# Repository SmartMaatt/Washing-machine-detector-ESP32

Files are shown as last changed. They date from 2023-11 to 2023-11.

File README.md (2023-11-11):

<h1 align="center">
    Alarm Amplifier Project
</h1>

<p align="center">
  <a href="#overview">Overview</a> •
  <a href="#hardware">Hardware</a> •
  <a href="#software">Software</a> •
  <a href="#usage-guide">Usage Guide</a> •
  <a href="#testing-and-troubleshooting">Testing and Troubleshooting</a> •
  <a href="#license">License</a>
</p>

<p align="center">
  
  
</p>

## Overview

This project involves the development of an alarm amplifier system designed to monitor the light status of household appliances using photoresistors. It reacts to changes in light with an audio alarm and Bluetooth console notifications. The system is built around the ESP32 microcontroller, incorporating features like Wi-Fi and Bluetooth connectivity.

## Hardware

### Components

- **ESP32 Microcontroller**: Central processing unit of the system, equipped with Wi-Fi and Bluetooth modules.
- **MAX99357 Audio Amplifier**: Converts digital signals into analog sound for the speaker.
- **Photoresistors**: Detects the light status from household appliances.
- **10kOhm Resistors**: Used in conjunction with the photoresistors to create a voltage divider.
- **B3F-1000S Button**: Manual reset button for the alarm system.

Hardware Components Image
*Hardware Components*

### Circuit Diagram

The following is the circuit diagram of the alarm amplifier system:

Circuit Diagram Image
*Circuit Diagram*

## Software

### Source Code

The project's source code is written in C and utilizes the Arduino IDE for development. Key libraries include:

- `AudioOutputI2S.h`
- `AudioFileSourcePROGMEM.h`
- `AudioGeneratorFLAC.h`
- `BluetoothSerial.h`

### Main Functionalities

- **Initial Setup**: Initializes the system and sets up Bluetooth and audio configurations.
- **Loop Function**: Manages the reading of sensor data, Bluetooth inputs, and alarm triggering.
- **Alarm Management**: Handles the audio alarm based on sensor input and allows manual reset.

### Bluetooth Commands

- `input1`, `input2`, `input3`: Activate/deactivate specific sensors.
- `ShowData`: Display current sensor data and status.
- `stop`: Stop the current alarm.

## Installation and Setup

To install and set up the software on your ESP32 microcontroller, follow these steps:

1. **Software Requirements**:
   - Ensure you have the latest version of the Arduino IDE installed on your computer. It can be downloaded from the [Arduino website](https://www.arduino.cc/en/software).

2. **ESP32 Board Manager Installation**:
   - Open the Arduino IDE.
   - Go to File > Preferences and in the "Additional Board Manager URLs" field, add the following URL: `https://dl.espressif.com/dl/package_esp32_index.json`.
   - Open the Board Manager by going to Tools > Board > Boards Manager, search for ESP32, and install the latest version.

3. **Connect the ESP32 to Your Computer**:
   - Using a micro USB cable, connect the ESP32 to your computer. Ensure that the ESP32 is powered on.

4. **Select the Correct Board and Port**:
   - In the Arduino IDE, go to Tools > Board and select the appropriate ESP32 board (e.g., ESP32 Dev Module).
   - Go to Tools > Port and select the COM port that the ESP32 is connected to.

5. **Load the Software**:
   - Open the project source code in the Arduino IDE.
   - If any additional libraries are required (as mentioned in the Software section), make sure they are installed.

6. **Compile and Upload**:
   - Click the "Upload" button in the Arduino IDE to compile the code and upload it to the ESP32.
   - Wait for the message "Done uploading" to appear in the IDE's console window.

7. **Verify Operation**:
   - After the code is successfully uploaded, the ESP32 should start running the program.
   - Monitor the Serial Monitor in the Arduino IDE for any debug information or confirmation messages.

8. **Bluetooth Pairing**:
   - On your smartphone or Bluetooth-enabled device, turn on Bluetooth and search for new devices.
   - Find the "Washing Machine Detector" and pair with it.
   - Once paired, you can use Bluetooth terminal applications to send commands to the ESP32.

If you encounter any issues during installation, refer to the Troubleshooting section for guidance.

## Usage Guide

To effectively utilize the alarm amplifier system, follow these steps:

1. **Power Connection**: Connect the system to a power source using the micro USB port on the ESP32.
2. **Mounting**: Attach the system near your chosen appliance, ensuring the photoresistors are positioned to accurately detect the appliance's light status.
3. **Bluetooth Connection**: Use a smartphone or computer with Bluetooth to connect to the system. The default Bluetooth name is "Washing Machine Detector".
4. **Sensor Configuration**: Via the Bluetooth terminal, send commands to activate or deactivate the sensors based on your needs. Use `input1`, `input2`, and `input3` commands to control respective sensors.
5. **Monitoring**: The system will now monitor the light signals from the appliance and trigger the alarm when specific conditions are met.
6. **Responding to Alarms**: When the alarm sounds, indicating the completion of an appliance's cycle, you can turn it off using the manual button on the system or through the Bluetooth command `stop`.
7. **Resetting the System**: After stopping the alarm, the system will reset to its initial state with all sensors deactivated. Reactivate the desired sensors to continue monitoring.

## Testing and Troubleshooting

### Testing Process

1. **Functional Testing**: Each component (microcontroller, audio amplifier, photoresistors) was individually tested for functionality before integration.
2. **Integration Testing**: The complete system was tested to ensure all components worked together seamlessly.
3. **Scenario Testing**: Simulated various appliance statuses (light on/off) to test the system's response and the accuracy of sensor readings.
4. **Usability Testing**: Non-technical users tested the system to ensure user-friendliness and ease of setup and operation.
5. **Longevity Testing**: Operated the system over extended periods to ensure durability and consistent performance.

### Troubleshooting

- **Bluetooth Connectivity Issues**: Ensure the device is within range and the ESP32 is powered correctly. Restart the Bluetooth connection if necessary.
- **False Alarms**: Check the positioning of the photoresistors. Ensure they accurately detect the appliance's light without interference from external light sources.
- **System Not Responding**: Verify the power supply and connections. Check for any loose connections in the circuit.

## Conclusions

1. **Functionality**: The system successfully detects the light status from appliances and triggers an alarm, demonstrating effective integration of hardware and software components.
2. **User-Friendly Design**: Testing with non-technical users highlighted the system's user-friendly design and easy setup process.
3. **Challenges Overcome**: Initially faced challenges with integrating sound playback and Bluetooth connectivity. These were resolved through software modifications, improving the system's reliability.
4. **Technical Skills Enhanced**: Gained significant experience in microprocessor systems, circuit design, and practical problem-solving.
5. **Future Improvements**: Potential enhancements include refining the user interface for Bluetooth control and expanding compatibility with a wider range of appliances.

This project has been a comprehensive learning journey, enhancing both technical skills and practical problem-solving abilities in the field of microprocessor systems and IoT applications.

## License
This project is licensed under the MIT License - see the [LICENSE](LICENSE) file for details.

---
&copy; 2023 Mateusz Płonka (SmartMatt). All rights reserved.
<a href="https://smartmatt.pl/">
    SmartMatt Logo
</a>

<p align="left">
  <a href="https://smartmatt.pl/">Portfolio</a> •
  <a href="https://github.com/SmartMaatt">GitHub</a> •
  <a href="https://www.linkedin.com/in/mateusz-p%C5%82onka-328a48214/">LinkedIn</a> •
  <a href="https://www.youtube.com/user/SmartHDesigner">YouTube</a> •
  <a href="https://www.tiktok.com/@smartmaatt">TikTok</a>
</p>

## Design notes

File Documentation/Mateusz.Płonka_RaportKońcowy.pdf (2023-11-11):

| Instytut Informatyki Politechniki Śląskiej Zespół Mikroinformatyki i Teorii Automatów Cyfrowych

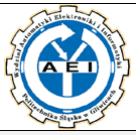
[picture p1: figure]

Rok akademicki: | Rodzaj studiów*: SSI/NSI/NSM | Przedmiot (Języki Asemblerowe/SMiW): | Grupa | Sekcja
2020/2021 | SSI | SMiW | 3 | 1
Imię: | Mateusz | Prowadzący: OA/JP/KT/GD/BSz/GB | JP
Nazwisko: | Płonka

# Raport końcowy

Temat projektu:

# Wzmacniacz alarmu

Data oddania:
dd/mm/rrrr | 12/02/2021

## 1. Opis założeń

Zadaniem projektu jest obserwacja diod sprzętów AGD przy pomocy fotorezystorów oraz reakcje na zmianę światła w postaci alarmu oraz powiadomień na konsoli Bluetooth.
Po dostarczeniu zasilania mikrokontroler wydaje dźwięk sygnalizujący poprawną konfigurację po czym rozpoczyna obserwację światła poprzez trzy podpięte i odpowiednio skonfigurowane programowo fotorezystory. Domyślnie na starcie aktywowany jest sensor nr 1, pozostałe odbierają światło, ale nie aktywują alarmu. Konfigurację można zmienić w czasie rzeczywistym przy pomocy konsoli Bluetooth, która umożliwia wyłączenie/włączenie odpowiedniego czujnika w zależności od potrzeb oraz wyświetlenie danych odbieranych przez system.
W przypadku spełnienia założeń co do poziomów światła określonych dla danych czujników (na przykład dioda na pralce przestanie świecić → pranie skończone), aktywowany zostaje alarm dźwiękowy oraz dostarczane jest powiadomienie na konsolę. Tryb alarmu można wyłączyć poprzez wciśnięcie przycisku znajdującego się na płytce lub używając terminala Bluetooth. Układ po wyjściu z alarmu, wraca do poprzedniego stanu.

## 2. Analiza zadania

Dobór elementów:
a) Mikrokontroler – ESP32
Wybrałem Esp-32 Wroom wyposażony w moduły Wi-FI oraz BT. Pomimo gabarytów oraz ceny uważam, że jest wart uwagi ze względu na rozwiązania, które umożliwia. Wbudowany moduł BT pozwoli na przystępną kontrolę, łączenie oraz zarządzanie z komponentami jak np. głośnik czy prosta aplikacja kontrolna na androida.
Napięcie zasilania 3,3V-5V, idealne dla wykorzystywanych komponentów w dodatku z wbudowanym konwerterem napięcia oraz portem micro-usb co pozwoli na uniwersalne i komfortowe wykorzystywanie urządzenia przez każdego i w każdym domu. Dodatkowo wbudowana pamięć flash o wartości 514kb idealnie posłuży do przechowywania krótkiego (2sek) pliku audio do odtworzenia w pętli po rozpoznaniu sygnału.
b) Wzmacniacz audio
Element jest wykorzystany do przetwarzania sygnału cyfrowego, nagranego na pamięć mikroprocesora sygnału dźwiękowego w postaci dzwonka, na dźwięk w postaci analogowej odtwarzany następnie przez głośnik podpięty do układu. Zdecydowałem się na MAX99357, pomimo dostawy z Chin, ze względu mniejszą objętość, dodatkowe elementy w zestawie oraz napięcie wejściowe 5V przy minimum 8V w konkurencyjnym elemencie.
c) Fotorezystory i rezystory
Trzy oddzielnie działające fotorezystory wykorzystane zostały w celu odczytywania zapalonej bądź zgaszonej diody sprzętu AGD. Możliwość wyłączania odpowiedniej komórki oraz reakcji na włączone lub wyłączone światło jest możliwa do zmiany software’owo w aplikacji. Rezystory 10kOhm wykorzystane zostały do utworzenia prostego dzielnika napięcia w celu wytworzenia sygnału cyfrowego.
d) Przycisk wyłączający alarm
Dodatkowa opcja (poza aplikacją) manualnego wyłączenia sygnału dźwiękowego po rozpoznaniu końca pracy sprzętu AGD. Wykorzystany został przycisk B3F-1000S.

## 3. Specyfikacja wewnętrzna

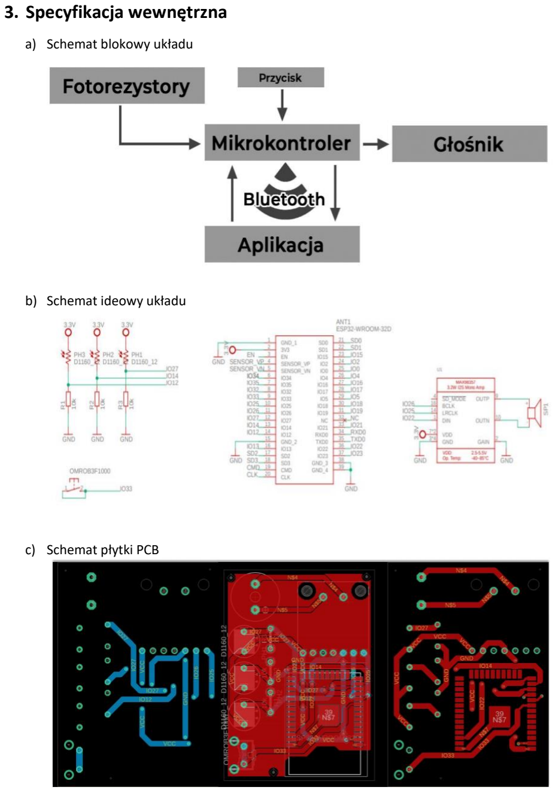
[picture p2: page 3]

a) Schemat blokowy układu
b) Schemat ideowy układu
c) Schemat płytki PCB d) Lista wykorzystanych elementów (wraz z kosztorysem)
Komponent | Nazwa elementu | Cena [PLN]
Mikroprocesor | ESP32-DEVKITC-32D (KIT) | 50,68
Dekoder stereo | MAX98357A | 24,90
Fotorezystory | PGM1200 THT | 13,53
Przycisk | B3F1000S OMRON OCB THT | 1,51
Rezystory | CFR0W4J0103A50 ROYAL 10kΩ | 21,38
Płytka uniwersalna | PP-UM26 | 24,10
Dostawa | | ~10
| | Suma: 146,10
e) Algorytm oprogramowania urządzenia

Część programowa projektu składa się z dwóch plików: Photores.ino zawierająca logikę działania programu oraz sample.h, w którym znajduje się zdekodowany do poziomu hex dźwięk alarmu w rozszerzeniu .flac.

Funkcja void setup() zawiera standardową inicjalizację oraz utworzenie obiektów zarządzających dźwiękiem.

Funkcja void loop() obsługuje kolejno: odczyt przycisku resetu, odczyt danych z konsoli bluetooth i reakcje na nie, obsługę trybu alarmu, odczyt danych z sensorów (kolejno 1,2,3) i reakcje na nie.

Photores.ino

#include <Arduino.h>

#include <AudioOutputI2S.h> #include <AudioFileSourcePROGMEM.h> #include <AudioGeneratorFLAC.h>

#include "sample.h"

#include "BluetoothSerial.h"

//Definition required for bluetooth connection
#if !defined(CONFIG_BT_ENABLED) || !defined(CONFIG_BLUEDROID_ENABLED)

#error Bluetooth is not enabled! Please run `make menuconfig` to and enable it #endif

//Declaration of BT and audio export objects
BluetoothSerial SerialBT;
AudioOutputI2S *out;
AudioFileSourcePROGMEM *file; AudioGeneratorFLAC *flac;

//Declaration of ports for sensors and reset pin const int sens1Pin = 34;
const int sens2Pin = 35;
const int sens3Pin = 32;
const int resetPin = 19;

//Storage for sensors value int sens1Value = 0;
int sens2Value = 0;
int sens3Value = 0;
String message = ""; | //Stores message passed by BT
bool loundry = false; | //True if one of three sensors gets desired effect
bool isPlaying = false; | //For looping sound while alarm

//Disable/Enable sensors
bool input1 = true;
bool input2 = false;
bool input3 = false;
bool ShowData = false; //True - Print sensors values on BT console

/*SETUP*/
void setup()
{
Serial.begin(115200);
pinMode(resetPin, INPUT_PULLUP); // sets the digital pin 7 as input delay(100);

//Audio objects configuration
audioLogger = &Serial;
file = new AudioFileSourcePROGMEM( sample_flac, sizeof(sample_flac) ); out = new AudioOutputI2S();
out->SetGain(0.2);
flac = new AudioGeneratorFLAC();
flac->begin(file, out);

//Define BT name
SerialBT.begin("Washing machine detector"); Serial.println("Setup done");
}

/*LOOP*/
void loop()
{
if(!flac->loop()){
flac->stop();
isPlaying = false;
}

//Reset button reaction
if(!digitalRead(resetPin)) {

//Recreate sound managment object for reset delete file;
delete out;
delete flac;
file = new AudioFileSourcePROGMEM( sample_flac, sizeof(sample_flac) ); out = new AudioOutputI2S();
out->SetGain(0.2);
flac = new AudioGeneratorFLAC();
flac->begin(file, out);

//Clear all bool variables input1 = false;
input2 = false;
input3 = false;
isPlaying = false;
loundry = false;
}

//Reading from Bluetooth (if avaible) if (SerialBT.available()){

//Save input
char incomingChar = SerialBT.read();

//Convert to string variable if input exists if (incomingChar != '\n'){
message += String(incomingChar);
}
else{
message = "";
}
Serial.write(incomingChar);
}

// Check received message and control output accordingly //Turn of sensor 1 (/input1)
if (message == "input1"){
if(input1){
input1 = false;
SerialBT.println("Sensor 1 off!"); }
else{
input1= true;
SerialBT.println("Sensor 1 on!"); }
}

//Turn of sensor 2 (/input2)
else if(message == "input2"){ if(input2){
input2 = false;
SerialBT.println("Sensor 2 off!"); }
else{
input2= true;
SerialBT.println("Sensor 2 on!"); }
}

//Turn of sensor 3 (/input3)
else if(message == "input3"){ if(input3){
input3 = false;
SerialBT.println("Sensor 3 off!"); }
else{
input3= true;
SerialBT.println("Sensor 3 on!"); }
}

//Respond on stop input when no alarm else if(message == "stop"){ SerialBT.println("No alarm to finish!"); }

//Show current data of sensors (/ShowData) else if(message == "ShowData"){
ShowData = true;
}

//Respond to alarm (loops sound) if(loundry){

//If no sound executed, play again

if(!isPlaying){
//Set playing on true
isPlaying = true;

//Recreate sound object for reset (I could have place this in outer function) delete file;
delete out;
delete flac;
file = new AudioFileSourcePROGMEM( sample_flac, sizeof(sample_flac) ); out = new AudioOutputI2S();
out->SetGain(0.2);
flac = new AudioGeneratorFLAC();
flac->begin(file, out);
}

//Reading from Bluetooth (if avaible) if (SerialBT.available()){

//Save input
char incomingChar = SerialBT.read();

//Convert to string variable if input exists if (incomingChar != '\n'){
message += String(incomingChar);
}
else{
message = "";
}
Serial.write(incomingChar);
}

// Stop alarm and clear bool variables if (message =="stop"){
SerialBT.println("Alarm turned off!"); SerialBT.println("Sensor 1 off!"); SerialBT.println("Sensor 2 off!"); SerialBT.println("Sensor 3 off!"); loundry = false;
input1 = false;
input2 = false;
input3 = false;
}
delay(20);
}

/*SENSOR 1*/
sens1Value = analogRead(sens1Pin); //Get sensor data

//Value over limit -> no sensor
if(sens1Value > 4090){
Serial.println("Sensor 1: No Sensor!!!");
if(ShowData) {SerialBT.println("Sensor 1: No Sensor!!!");} }

//Value under 1500 -> led has been turned on, react...
else if(sens1Value < 1500){
//printing info on console and bt console Serial.println("Sensor 1: "+String(sens1Value));
if(ShowData) {SerialBT.println("Sensor 1: "+String(sens1Value));}

//...but only if this sensor is avaible
if(!loundry && input1)
{
loundry = true;
SerialBT.println("Task done! (1)"); }
}
//Rest of scenerios that aren't necessery right now

else{
Serial.println("Sensor 1: "+String(sens1Value));
if(ShowData) {SerialBT.println("Sensor 1: "+String(sens1Value));} }

//Print in Bt console if sensor is on or off
if(ShowData){
if(input1){
SerialBT.println("Sensor 1: On");
}
else{
SerialBT.println("Sensor 1: Off"); }
}

/*SENSOR 2*/
sens2Value = analogRead(sens2Pin); //Get sensor data

//Value over limit -> no sensor
if(sens2Value > 4090){
Serial.println("Sensor 2: No Sensor!!!");
if(ShowData) {SerialBT.println("Sensor 2: No Sensor!!!");} }

//Value between 4090 and 3000 to detect lack of light...
else if(sens2Value > 3000){
//printing info on console and bt console Serial.println("Sensor 2: "+String(sens2Value));
if(ShowData) {SerialBT.println("Sensor 2: "+String(sens2Value));}

//...but only if this sensor is avaible
if(!loundry && input2)
{
loundry = true;
SerialBT.println("Task done! (2)"); }
}

//Rest of scenerios that aren't necessery right now
else{
Serial.println("Sensor 2: "+String(sens2Value));
if(ShowData) {SerialBT.println("Sensor 2: "+String(sens2Value));} }

//Print in Bt console if sensor is on or off
if(ShowData){
if(input2){
SerialBT.println("Sensor 2: On");
}
else{
SerialBT.println("Sensor 2: Off"); }
}

/*SENSOR3 (not configured)*/
sens3Value = analogRead(sens3Pin); //Get sensor data

//Value over limit -> no sensor
if(sens3Value > 4090)
{
Serial.println("Sensor 3: No Sensor!!!");
if(ShowData) {SerialBT.println("Sensor 3: No Sensor!!!");} }
else
{
Serial.println("Sensor 3: "+String(sens3Value));
if(ShowData) {SerialBT.println("Sensor 3: "+String(sens3Value));}

}

//Print in Bt console if sensor is on or off if(ShowData){
if(input3){
SerialBT.println("Sensor 3: On");
}
else{
SerialBT.println("Sensor 3: Off");
}
}

Serial.println("-------------------------");
ShowData = false; //Clear show data variable after printing on Bt console }

## 4. Specyfikacja zewnętrzna

a) Opis funkcji wykorzystanych elementów
1. Mikrokontroler: służy do sterowania całym układem, zarządzania jego logiką, przechowywania w pamięci programu oraz efektów dźwiękowych do odtworzenia.
2. Fotorezystory: odbierają natężenie światła i interpretują je w przedziale [0, 4090] gdzie 0 oznacza możliwie najjaśniejszy sygnał do odebrania.
3. Głośnik: Powiadamia użytkownika o zakończeniu zadania i konieczności wyciągnięcia prania.
4. Przycisk: służy do ręcznego wyłączenia układu z trybu alarmu.
b) Reakcja oprogramowania na zdarzenie
Gdy do układu nie jest doprowadzone zasilanie, żadna z jego funkcjonalności nie jest dostępna dla użytkownika. Jak wiemy układ zasilany działa o wiele lepiej. Po dostarczeniu zasilania poprzez post micro USB układ aktywuje się, co sygnalizuje pojedynczym dźwiękiem.

Fotorezystory odbierają światło z otoczenia i interpretują je w postaci liczby w przedziale [0, 4090] gdzie „0” oznacza możliwie najjaśniejszy możliwy sygnał do odebrania.

Do skonfigurowania urządzenia należy użyć telefonu/komputera z terminalem bluetooth i aktywować sensory których przeznaczenie jest nam aktualnie potrzebne (każda wszczyna alarm w różnym paśmie światła). Domyślnie aktywowany jest tylko sensor nr 1.

Gdy dany sensor wykryje odpowiednie światło, wywoła się tryb alarmu w którym z głośnika wydawany jest dźwięk oraz wysyłana jest wiadomość na konsolę użytkownika. Po resecie (zdalnie lub poprzez przycisk), układ wraca do stanu 0 z wyłączonymi wszystkimi sensorami.

c) Instrukcja obsługi dla użytkownika
1. Podłącz układ do prądu i zamontuj go w sprzęcie AGD wybierając odpowiedni fotorezystor:
- nr 1 -> reakcja na pojawienie się światła
- nr 2 -> reakcja na zniknięcie światła
- nr 3 -> możliwy do własnej konfiguracji

2. Połącz układ z innym urządzeniem poprzez bluetooth i skonfiguruj odpowiednie sensory dla poprawnego działania:
Komendy
- stop – zatrzymaj alarm
- input(1-3) – aktywuje/dezaktywuje dany sensor
- ShowData – wyświetl informacje na temat aktualnie odbieranych wartości oraz stanu danych sensorów
3. Gdy dojdzie do spełnienia określonych warunków układ powiadamia użytkownika o zakończeniu pracy sprzętu, na przykład pralki, bądź piekarnika za pomocą sygnału dźwiękowego oraz powiadomienia poprzez Bluetooth, gdy podpięte jest urządzenie zdalne.
4. Sygnał dźwiękowy wyłącza się przyciskiem lub komendą, po czym układ resetuje się i wraca do stanu „0” gdzie każdy sensor jest zdezaktywowany.
5. By ponownie skorzystać z urządzenia należy ponownie aktywować pożądane sensory
d) Opis złączy i okablowania

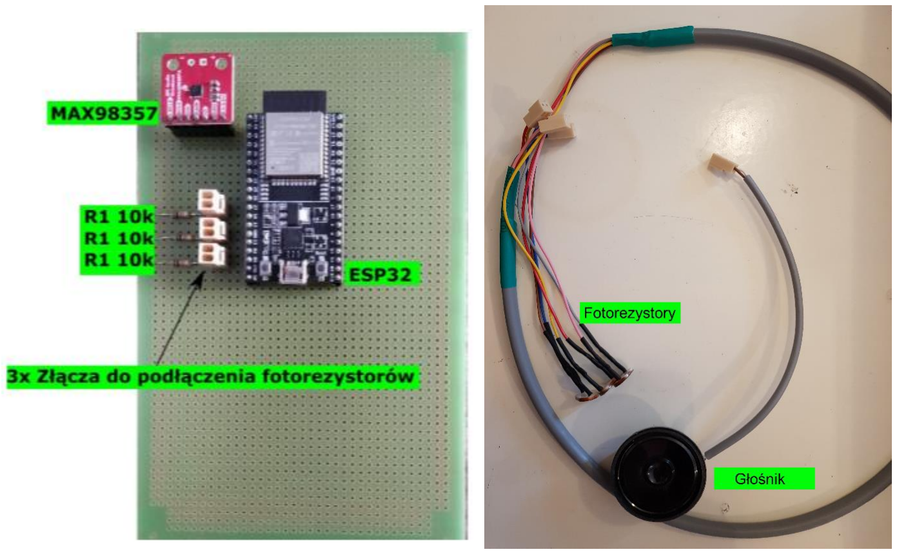
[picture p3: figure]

e) Opis montażu układu
Wszystkie elementy, zamówione na stronie tme.eu, zostały wlutowane w płytkę uniwersalną. Mikroprocesor, dekoder stereo oraz pomniejsze części jak rezystory czy złącza zostały wlutowane na górnej części płytki, pozostałe czyli głośnik i okablowane fotorezystory podpinane są do wspomnianych wcześniej portów.

f) Sposób programowania układu
Układ został zaprogramowany bez udziału programatora dzięki możliwości jaką udziela ESP32 czyli wprowadzenia danych bezpośrednio po micro USB. Projekt został napisany w języki C w środowisku Arduino. Do obsługi dźwięku zostały wykorzystane biblioteki AudioOutputI2S.h, AudioFileSourcePROGMEM.h, AudioGeneratorFLAC.h a do bluetootha BluetoothSerial.h.
g) Uruchamianie oraz testowanie
Ze względu na brak innych modułów jak Arduino, projekt był testowany już bezpośrednio na gotowym projekcie. Został on wielokrotnie sprawdzony pod względem wielu pokrętnych scenariuszy, które mogą się wydarzyć podczas obsługi sprzętu oraz przez osoby trzecie, nie mające nigdy kontaktu z mikroprocesorami, dla sprawdzenia przystępności obsługi układu.

## 5. Wnioski z przebiegu pracy

a) Testowanie poprawności działania urządzenia
Mimo prostej funkcjonalności układu przeprowadzone zostało wiele testów, w szczególności tych związanych z logiką działania programu i przystępnością obsługi niedzielnego użytkownika. Ze względu na brak innych modułów jak Arduino, projekt był testowany już bezpośrednio na gotowym projekcie. Układ był wielokrotnie poddawany różnym (często mało prawdopodobnym) scenariuszom by wykluczyć możliwość zdarzenia oraz został przez jeden dzień testowany przez osobę trzecią nie mającą nigdy kontaktu z mikroprocesorami czy IT w celu sprawdzenia czy jest przystępny w obsłudze.
b) Napotkane problemy
Za głównym problem uważam brak doświadczenia z konstrukcją i programowaniem układów tego typu. Jestem pewien że gdybym zabierał się za to teraz, zajęłoby mi to o wiele mniej czasu i wysiłku.

Pojawił się również problem związany z połączeniem odtwarzana dźwięku w pętli ze stałym połączeniem prze bluetooth. Wynikał on z niezgodności w użytych bibliotekach. Został on zażegnany programowo poprzez wprowadzenie odrobinę innej logiki polegającej na wyłączaniu/włączeniu sensorów gdy są potrzebne.

c) Wyniki końcowe
Projektowanie przedstawionego układu pozwoliło mi na poszerzenie wiedzy na temat tworzenia systemów mikroprocesorowych oraz z pewnością umożliwi mi zyskanie doświadczenia w procesie lutowania mikroelementów na płytce. Zarazem rozszerzając moją wiedzę związaną z realizacji takich układów w praktyce i skomplikowania tego procesu.

Proces tworzenia omówionego schematu będę z pewnością jeszcze długo dobrze wspominał, jednakże utwierdziło mnie to w przekonaniu że mikroprocesory są wymagającą gałęzią IT i nie czuje się na tyle kompetentny żeby wiązać z nią swoją przyszłość.

d) Literatura
https://docs.espressif.com/projects/esp-idf/en/latest/esp32/https://randomnerdtutorials.com/projects-esp32/https://github.com/earlephilhower/ESP8266Audiohttps://www.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 os (https://www.youtube.com/watch?v=RStncO3zb8g&feature=youtu.be&ab_channel=RuiSantos)

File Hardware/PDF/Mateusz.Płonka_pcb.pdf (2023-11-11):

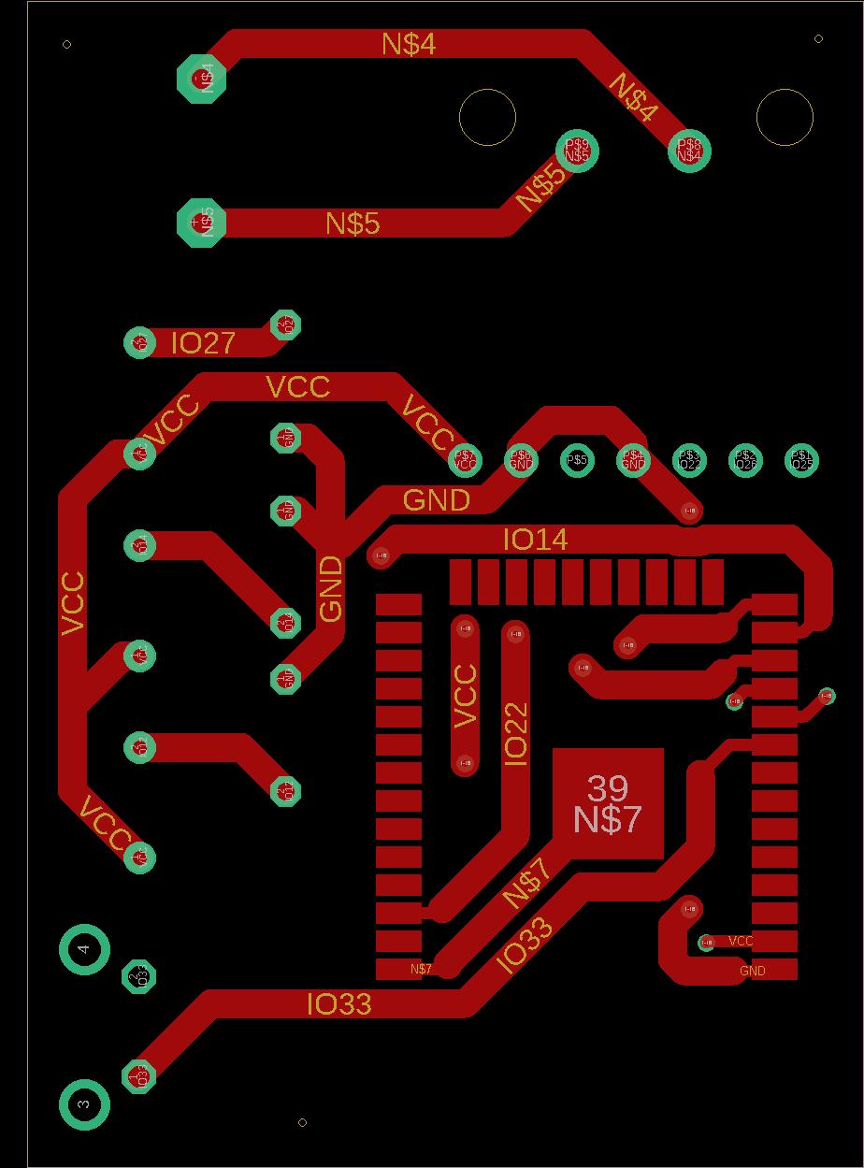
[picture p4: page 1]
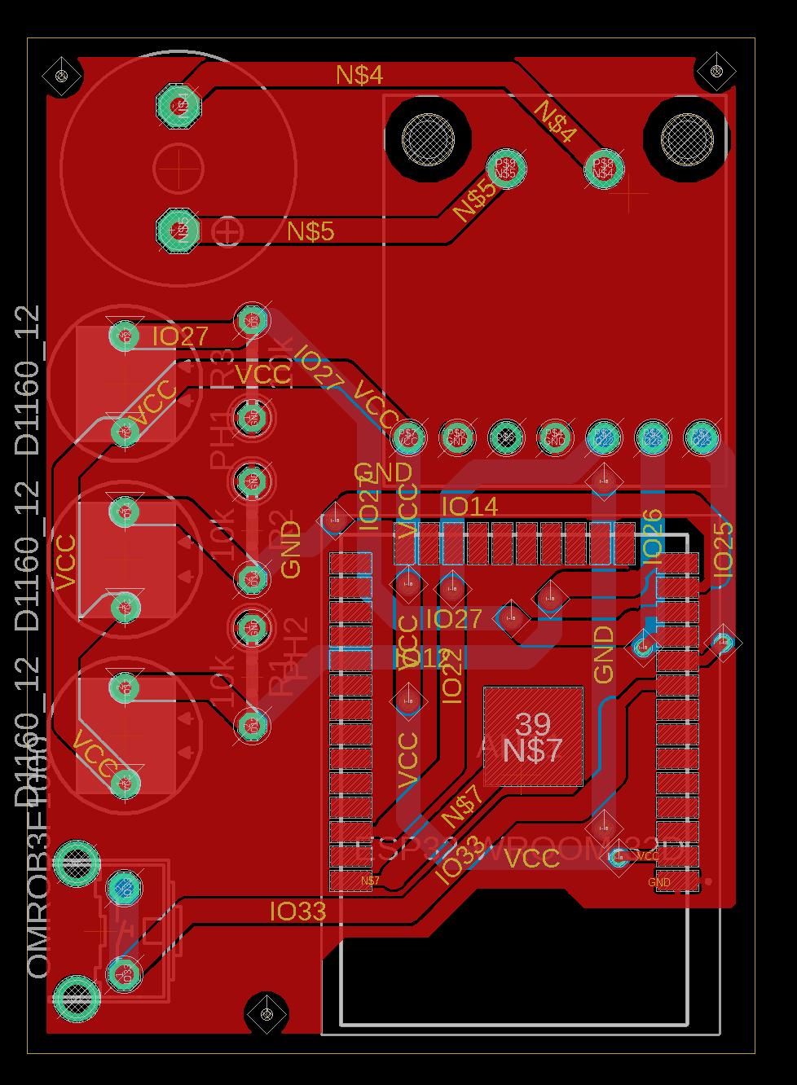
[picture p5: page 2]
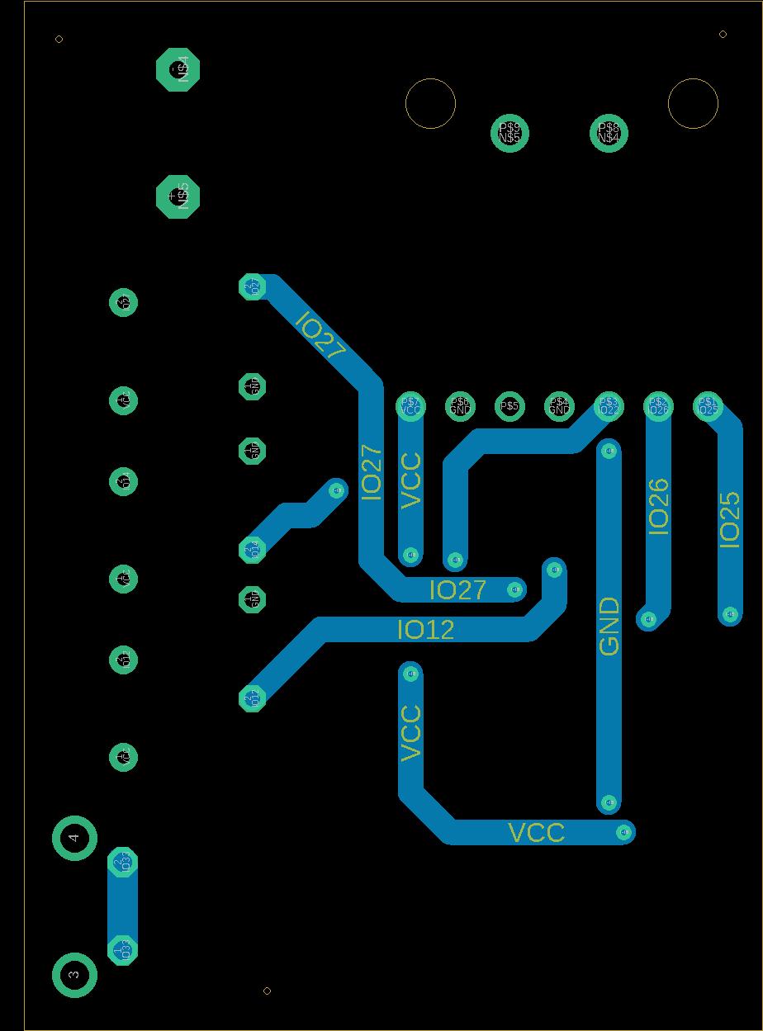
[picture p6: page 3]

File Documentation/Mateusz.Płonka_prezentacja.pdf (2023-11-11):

## WZMACNIACZ ALARMÓW URZĄDZEŃ AGD

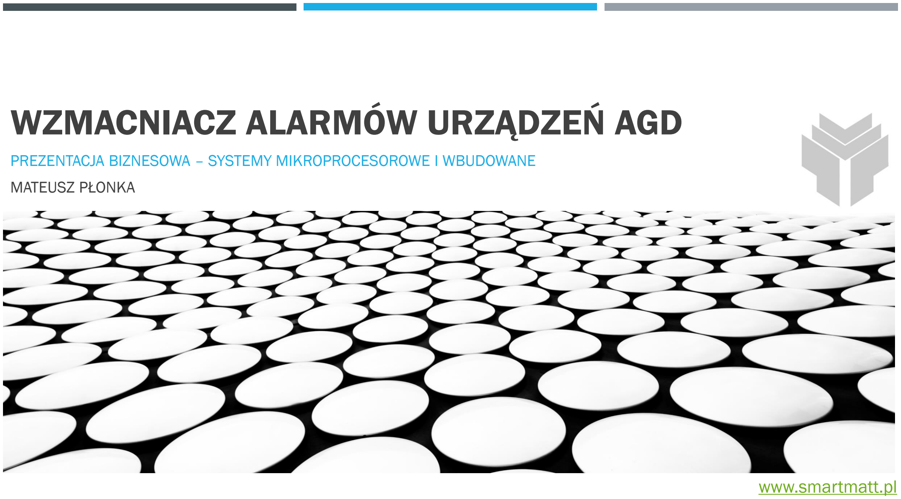
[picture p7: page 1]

PREZENTACJA BIZNESOWA – SYSTEMY MIKROPROCESOROWE I WBUDOWANE

MATEUSZ PŁONKA

www.smartmatt.pl

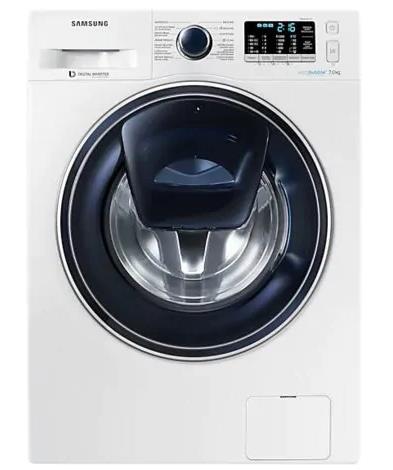
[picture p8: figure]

## ZAŁOŻENIA PROJEKTU

Celem projektu jest zaprojektowanie oraz
skonstruowanie | urządzenia | umożliwiającego
obserwację diod sprzętów AGD oraz reakcje na zmianę niego w postaci alarmu wraz z sygnałami świetlnymi.

Głównym zastosowaniem będzie wzmacnianie cichych alarmów urządzeń domowych takich jak pralka, bądź piekarnika.

## SCHEMAT BLOKOWY I ANALIZA

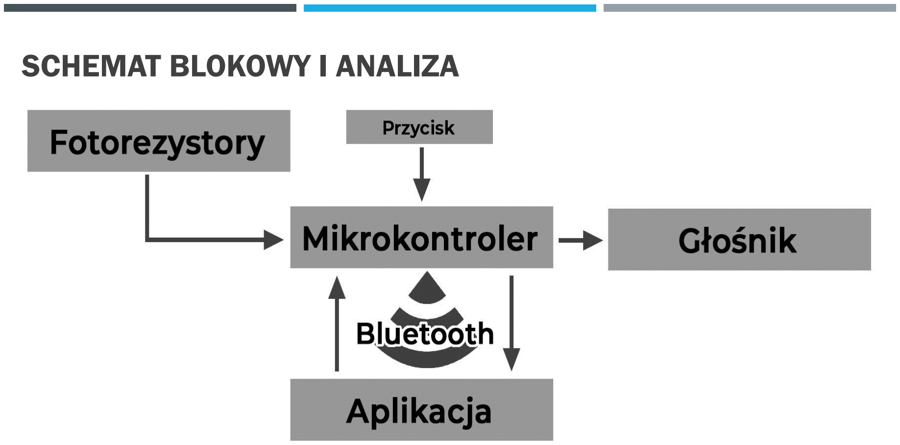
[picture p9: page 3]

## SCHEMAT IDEOWY

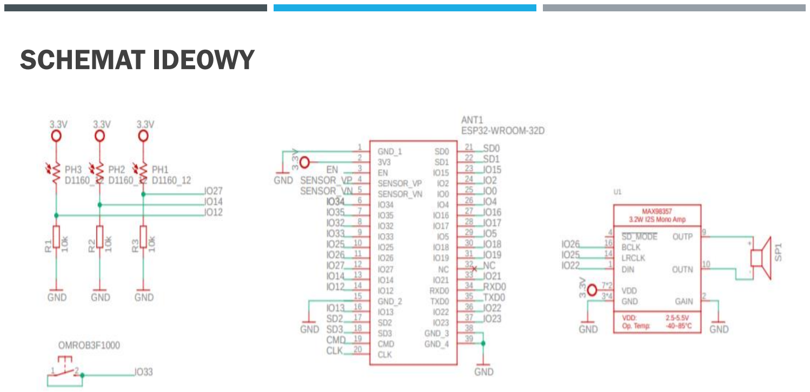
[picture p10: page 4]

## DOBÓR ELEMENTÓW

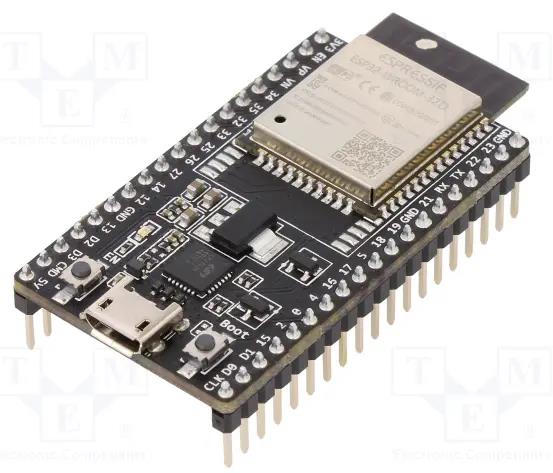
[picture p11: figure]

- Mikroprocesor: ESP32-DEVKITC-32D (KIT)
- Dekoder stereo: MAX98357A
- Fotorezystory: PGM1200 THT
- Przycisk: B3F1000S OMRON OCB THT
- Rezystory: CFR0W4J0103A50 ROYAL 10kΩ

## SCHEMAT PCB

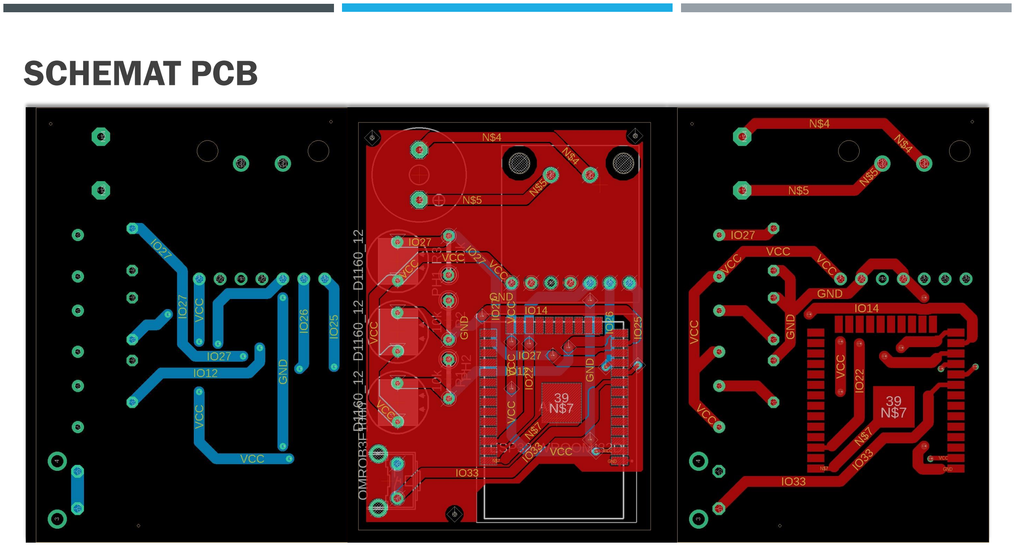
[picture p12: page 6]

## ROZMIESZCZENIE ELEMENTÓW NA PŁYTCE UNIWERSALNEJ

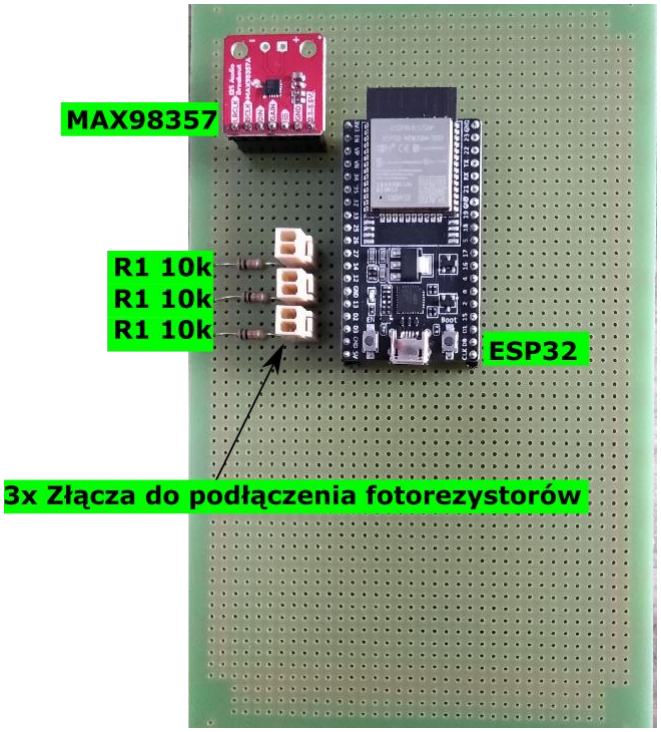
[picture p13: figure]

## KOSZTORYS

Komponent | Nazwa elementu | Cena
- Mikroprocesor: | ESP32-DEVKITC-32D (KIT) | 50,68 PLN
- Dekoder stereo: | MAX98357A | 24,90 PLN
- Fotorezystory: | PGM1200 THT | 13,53 PLN
- Przycisk: | B3F1000S OMRON OCB THT | 1,51 | PLN
- Rezystory: | CFR0W4J0103A50 ROYAL 10kΩ | 21,38 PLN
- Płytka uniwersalna: | PP-UM26 | 24,10 PLN
- Dostawa: | | ~10 | PLN

Suma: 146,10PLN

## DZIAŁANIE UKŁADU

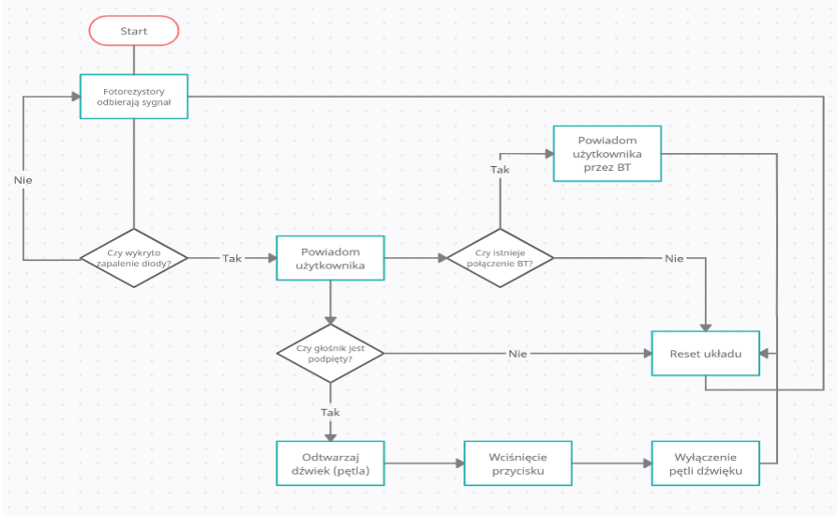
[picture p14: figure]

## INSTRUKCJA OBSŁUGI

1. Podłącz układ do prądu i zamontuj go w sprzęcie AGD.
2. System w czasie działania oczekuje zmiany diody w nasłuchiwanym urządzeniu.
3. Gdy dojdzie do zapalenia się diody układ powiadamia użytkownika o zakończeniu pracy sprzętu, na przykład pralki, bądź piekarnika za pomocą:
a) sygnału dźwiękowy, gdy podpięty jest głośnik,
b) powiadomienia poprzez Bluetootha, gdy podpięte jest urządzenie zdalne.
4. Sygnał dźwiękowy wyłącza się przyciskiem, po czym układ resetuje się i wraca do stanu początkowego.

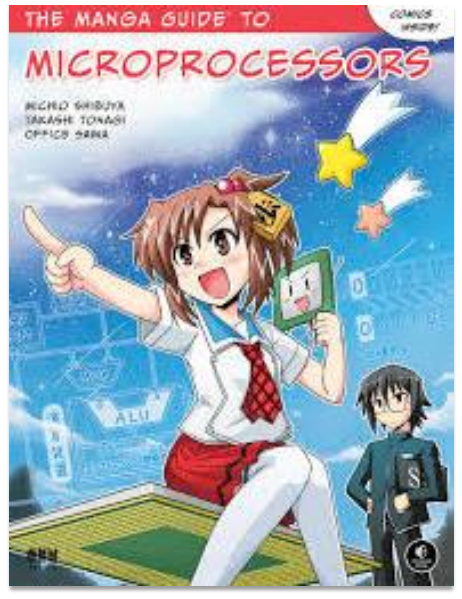
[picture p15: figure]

## WNIOSKI

Projektowanie przedstawionego układu pozwoliło mi na
poszerzenie | wiedzy | na | temat | tworzenia | systemów
mikroprocesorowych oraz z pewnością umożliwi mi zyskanie doświadczenia w procesie lutowania mikroelementów na płytce. Zarazem rozszerzając moją wiedzę związaną z realizacji takich układów w praktyce i skomplikowania tego procesu.

Proces tworzenia omówionego schematu będę z pewnością jeszcze długo dobrze wspominał, jednakże utwierdziło mnie to w przekonaniu że mikroprocesory są wymagającą gałęzią IT i nie czuje się na tyle kompetentny żeby wiązać z nią swoją przyszłość.

# DZIĘKUJĘ ZA UWAGĘ!

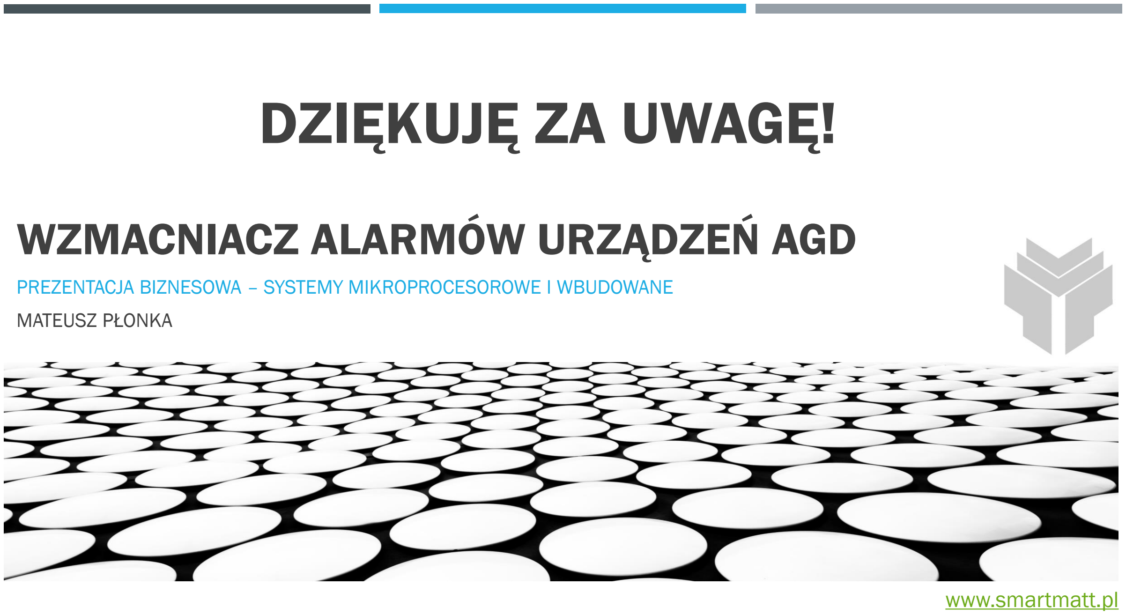
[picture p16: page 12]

## WZMACNIACZ ALARMÓW URZĄDZEŃ AGD

PREZENTACJA BIZNESOWA – SYSTEMY MIKROPROCESOROWE I WBUDOWANE

MATEUSZ PŁONKA

www.smartmatt.pl

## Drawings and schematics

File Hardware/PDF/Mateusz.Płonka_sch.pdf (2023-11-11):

A

A

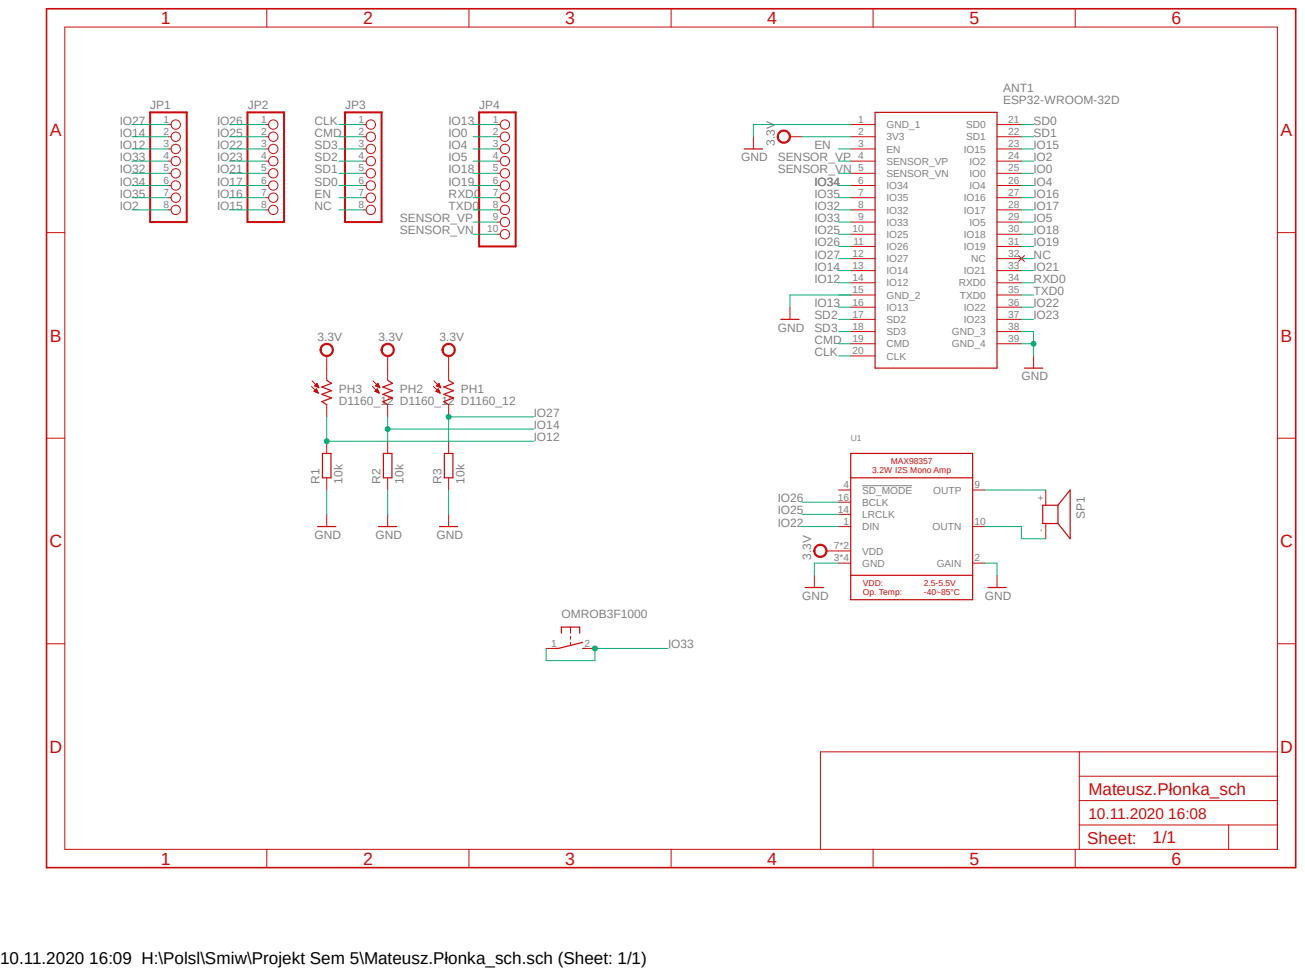
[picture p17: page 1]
GND; ESP32-WROOM-32D; GND ³.3V; GND³.3V; SP¹; GND_1 1; SENSOR_VP 4; SENSOR_VN 5; GND_2 15; CMD 19; CLK 20; 33 RXD0; 34 TXD0; 37 GND_3; 38 GND_4; ANT1; SD_MODE 4; BCLK 16; DIN 1; GAIN; 2 GND 3*4; LRCLK 14; OUTN; 10 OUTP; 9 VDD 7*2 U1; 1 2 OMROB3F1000; SENSOR_VP; SENSOR_VN; CMD; CLK; TXD0; RXD0; Sheet:; Mateusz.Płonka_sch; MAX98357; 3.2W I2S Mono Amp VDD: Op. Temp:

10.11.2020 16:09 H:\Polsl\Smiw\Projekt Sem 5\Mateusz.Płonka_sch.sch (Sheet: 1/1)

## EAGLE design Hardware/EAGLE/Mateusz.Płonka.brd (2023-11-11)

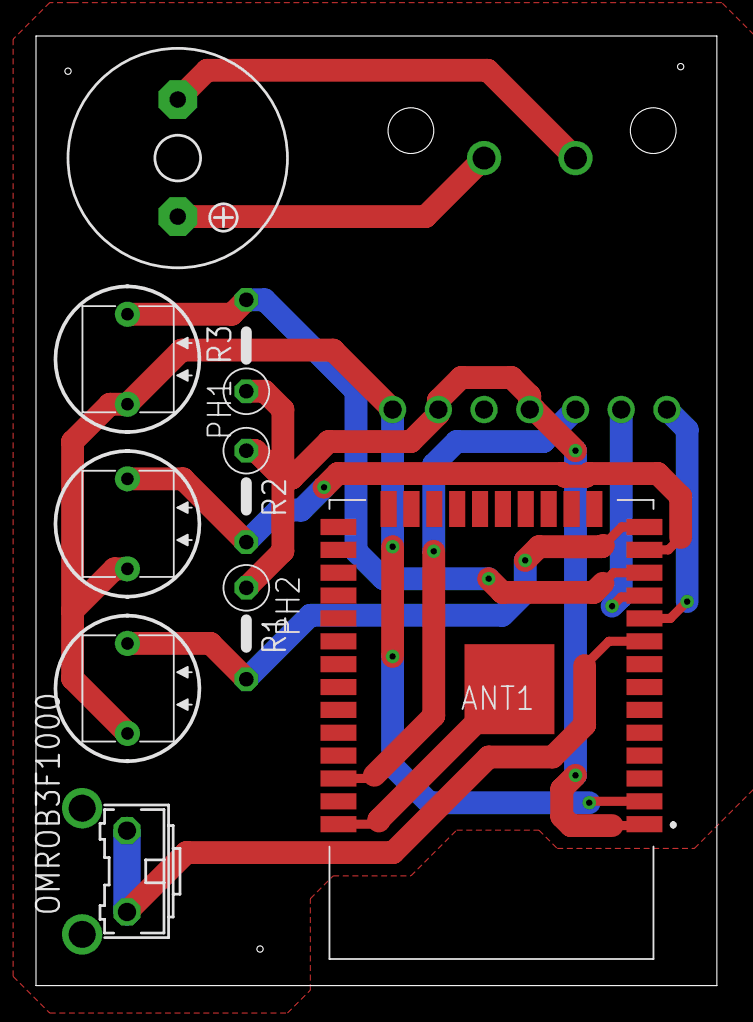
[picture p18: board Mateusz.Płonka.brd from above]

Board: 2 copper layers, 37.8 x 52.8 mm, 10 parts (1 on the bottom side), 12 nets.

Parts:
ANT1: ESP32-WROOM-32D; ESP32WROOM32D
OMROB3F1000: B3F-31XX
PH1, PH2, PH3: D1160_12; D11XX
R1, R2, R3: 10k; 0207/5V
SP1: KSS1201
U1: KRZYSZTOF.KOCOT_ADAFRUIT-MAX98357-BREAKOUT_MICROBUILDER_QFN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

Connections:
GND: ANT1.1, R1.1, R2.1, R3.1, U1.P$4, U1.P$6
IO12: ANT1.14, PH3.2, R1.2
IO14: ANT1.13, PH2.2, R2.2
IO22: ANT1.36, U1.P$3
IO25: ANT1.10, U1.P$1
IO26: ANT1.11, U1.P$2
IO27: ANT1.12, PH1.2, R3.2
IO33: ANT1.9, OMROB3F1000.1, OMROB3F1000.2
unnamed: SP1.-, U1.P$8
unnamed: SP1.+, U1.P$9
unnamed: ANT1.38, ANT1.39
VCC: ANT1.2, PH1.1, PH2.1, PH3.1, U1.P$7

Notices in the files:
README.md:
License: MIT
